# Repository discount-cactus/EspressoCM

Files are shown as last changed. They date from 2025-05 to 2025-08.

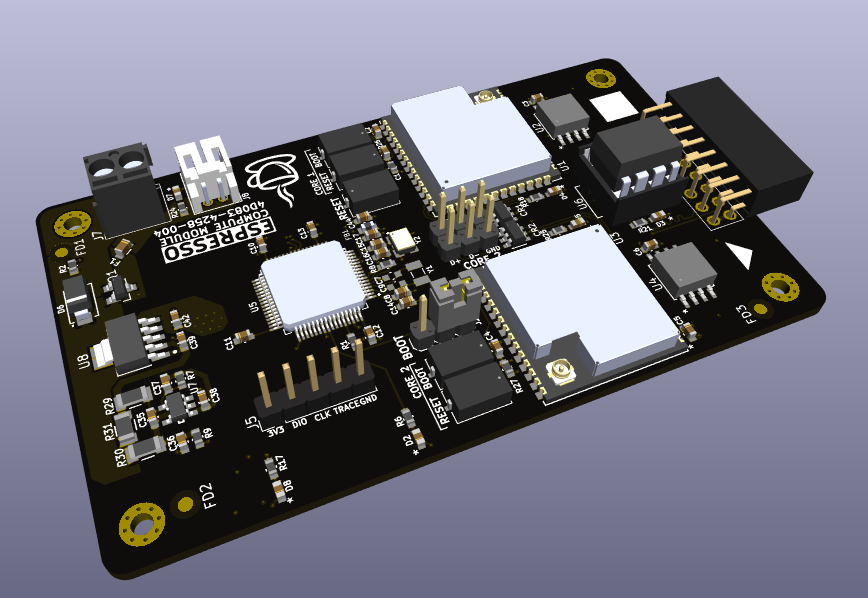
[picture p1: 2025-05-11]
cad_render.png

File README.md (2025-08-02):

# EspressoCM
Espresso Rev 4 CM, or just Espresso CM, is an STM32- and ESP32-based compute module for high performance networking and automation applications. The board was designed to provide a plethora of capabilities in a small, user-friendly and cheap package. An STM32 and two (not one but two!) ESP32's were chosen for their ease-of-use, clock speed and peripherals to acommodate these requirements. For the beginner or novel hobbyist, the ESP32's can be used - both come with their own dedicated flash memory chip as well as Wi-Fi and Bluetooth connectivity. For the more advanced and tech-savy, the STM32 can be programmed directly for higher-performance control.

Link to EspressoCM's complimentary library: https://github.com/discount-cactus/EspressoCMlib



## Board Statistics
- Dimensions: 84.9mm x 50.2mm
- Layers: 4
- Components: 83
- Mounting Hole Size: M2

## Features
- 1 x STM32F107 (@72MHz)
- 2 x ESP32-S3 (@240MHz)
- 1 x ATtiny85
- 1.5A linear regulator (VIN: 3-20V)
- Automatic power switchover from terminal block `J7` and JST battery connector `J8`
- JST LiPo Battery Connector
- 128Mbit Flash (one per ESP32)
- Dedicated E2B functionality
- On-board current sensing

## Applications
- Smart Homes
- Home networks
- IoT Connectivity
- Home automation
- Sensor monitoring

## Programming
### STM32
- The STM32 is programmed on-board via the pin connector `J5` with an ST-Link V2.
- Verify STM32CubeIDE is up-to-date
- Verify ST-Link V2 is up-to-date
1. Set BOOT0 to HIGH
2. Push reset button
3. Build code
4. Run code
5. Set BOOT0 to LOW
6. Push reset button

### ESP32
- The ESP32's are programmed on-board via the header pins `J3` (for Core 1) and `J4` (for Core 2). Pins are labeled on silkscreen.

### ATtiny85
- The ATtiny85 is programmed off-board.

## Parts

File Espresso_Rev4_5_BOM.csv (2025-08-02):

# | Reference | Qty | Value | Footprint | Manufacturer | Part Number | Alt Part Number | Rating | Color | DNP | Voltage Rating
1 | C14 | 1 | 4.7uF | Custom_Microcontroller:C_0603 | Samsung | CL10A475MA8NQNC |  | 25V
2 | C40 | 1 | 4.7nF | Custom_Microcontroller:C_1206 | KEMET | C1206C472KDRACAUTO |  | 1kV |  | DNP
3 | C1,C4 | 2 | 1uF | Custom_Microcontroller:C_0603 | Samsung | CL10A105KB8NNNC |  | 50V
4 | C15,C16 | 2 | 20pF | Custom_Microcontroller:C_0603 | Samsung | CL10C200JB8NNNC |  | 50V
5 | C2,C3,C5,C6,C8,C10,C11,C12,C13,C17,C38,C44 | 12 | 100nF | Custom_Microcontroller:C_0603 | Samsung | CL10B104KB8NNNC |  | 50V
6 | C35,C36,C37 | 3 | 220pF | Custom_Microcontroller:C_0603 | Samsung | CL10B221KB8NFNC | C0603C221J5HACAUTO | 50V
7 | C39,C42 | 2 | 10uF | Custom_Microcontroller:C_0603 | Samsung | CL10A106MA8NRNC |  | 25V
8 | C7,C9 | 2 | 8pF | Custom_Microcontroller:C_0603 | Samsung | CL10C080DB81PNC |  | 50V |  | DNP
9 | CR1,CR2 | 2 | USBLC6-2SC6 | Custom_Microcontroller:USBLC6-2SC6 | STMicroelectronics | USBLC6-2SC6
10 | D6 | 1 | ~ | Custom_Microcontroller:SK54AHE3-LTP | MCC | SK54AHE3-LTP
11 | D1,D4,D5 | 3 | ~ | Custom_Microcontroller:LED_0603 | Lite-On Inc. | LTST-C191KGKT |  |  | Green
12 | D2,D3,D7,D8 | 4 | ~ | Custom_Microcontroller:LED_0603 | Lite-On Inc. | LTST-C191KFKT |  |  | Orange
13 | F1 | 1 | 1A | Custom_Microcontroller:MF-FSMF050X-2 | Bourns | MF-FSMF050X-2
14 | FB1 | 1 | 120R | Custom_Microcontroller:FB_0603 | Murata | BLM18KG121TN1D
15 | J1 | 1 | ~ | Custom_Microcontroller:2X8 | Sullins | PPTC082LJBN-RC
16 | J5 | 1 | Conn_01x05 | Connector_PinHeader_2.54mm:PinHeader_1x05_P2.54mm_Vertical
17 | J6 | 1 | 20021321-00030T4LF | Custom_Microcontroller:20021321-00030T4LF | Amphenol | 20021321-00030T4LF
18 | J7 | 1 | OSTTE020104 | Custom_Microcontroller:OSTTE020104 | On Shore Technology | OSTTE020104 |  | 10A
19 | J8 | 1 | S2B-PH-K-S | Custom_Microcontroller:S2B-PH-K-S | JST | S2B-PH-K-S
20 | J2,J3,J4 | 3 | ~ | Custom_Microcontroller:1X3
21 | Q1 | 1 | ~ | Custom_Microcontroller:DMP3099L-7 | Diodes | DMP3099L-7
22 | R2 | 1 | 100K | Custom_Microcontroller:R_0603 | Stackpole | RMCF0603FT100K |  | 1/10W
23 | R3 | 1 | 1M00 | Custom_Microcontroller:R_1206 | Stackpole | RMCF1206FG1M00 |  | 1/4W |  | DNP
24 | R8 | 1 | 1M00 | Custom_Microcontroller:R_0603 | Stackpole | RMCF0603FT1M00 |  | 1/10W
25 | R31 | 1 | 3mOhm | Custom_Microcontroller:R_1206 | Rohm Semiconductor | PMR18EZPFV3L00 |  | 1W
26 | R1,R26,R27 | 3 | 10K | Custom_Microcontroller:R_0603 | Stackpole | RMCF0603FT10K0 |  | 1/10W
27 | R29,R30 | 2 | 97R6 | Custom_Microcontroller:R_1206 | KOA Speer | RK73H2BTTD97R6F |  | 1/4W
28 | R4,R22,R23,R28 | 4 | 4K7 | Custom_Microcontroller:R_1206 | Stackpole | RMCF1206FT4K70 |  | 1/4W
29 | R5,R6,R17,R18,R21,R24,R25 | 7 | 1K | Custom_Microcontroller:R_0603 | Stackpole | RMCF0603FT1K00 |  | 1/10W
30 | R7,R9 | 2 | 73K2 | Custom_Microcontroller:R_0603 | Stackpole | RMCF0603FT73K2 |  | 1/10W
31 | SW1,SW2,SW3,SW4,SW5 | 5 | ~ | Custom_Microcontroller:PTS636 SK25J SMTR LFS | C&K | PTS636SK25JSMTR LFS
32 | U5 | 1 | STM32F107RCT6TR | Custom_Microcontroller:STM32F107RCT6TR | STMicroelectronics | STM32F107RCT6TR
33 | U6 | 1 | ATTINY85-20PU | Custom_Microcontroller:ATTINY85-20PU | Microchip | ATTINY85-20PU
34 | U7 | 1 | INA180A2QDBVRQ1 | Custom_Microcontroller:INA180A2QDBVRQ1 | Texas Instruments | INA180A2QDBVRQ1
35 | U8 | 1 | TPS7A4533DCQR | Custom_Microcontroller:TPS7A4533DCQR | Texas Instruments | TPS7A4533DCQR
36 | U1,U3 | 2 | ESP32-S3-WROOM-1U-N8R2 | Custom_Microcontroller:ESP32-S3-WROOM-1U-N8R2 | Espressiff | ESP32-S3-WROOM-1U-N8R2
37 | U2,U4 | 2 | ~ | Custom_Microcontroller:W25Q128JVSIQ | Winbond | W25Q128JVSIQ
38 | Y1 | 1 | 32.768 kHz | Custom_Microcontroller:ECS-.327-9-34B-TR | ECS | ECS-.327-9-34B-TR |  |  |  | DNP
39 | Y2 | 1 | 25MHz | Custom_Microcontroller:ECS-2333-250-BN-TR | ECS | ECS-250-20-33-CKM-TR3

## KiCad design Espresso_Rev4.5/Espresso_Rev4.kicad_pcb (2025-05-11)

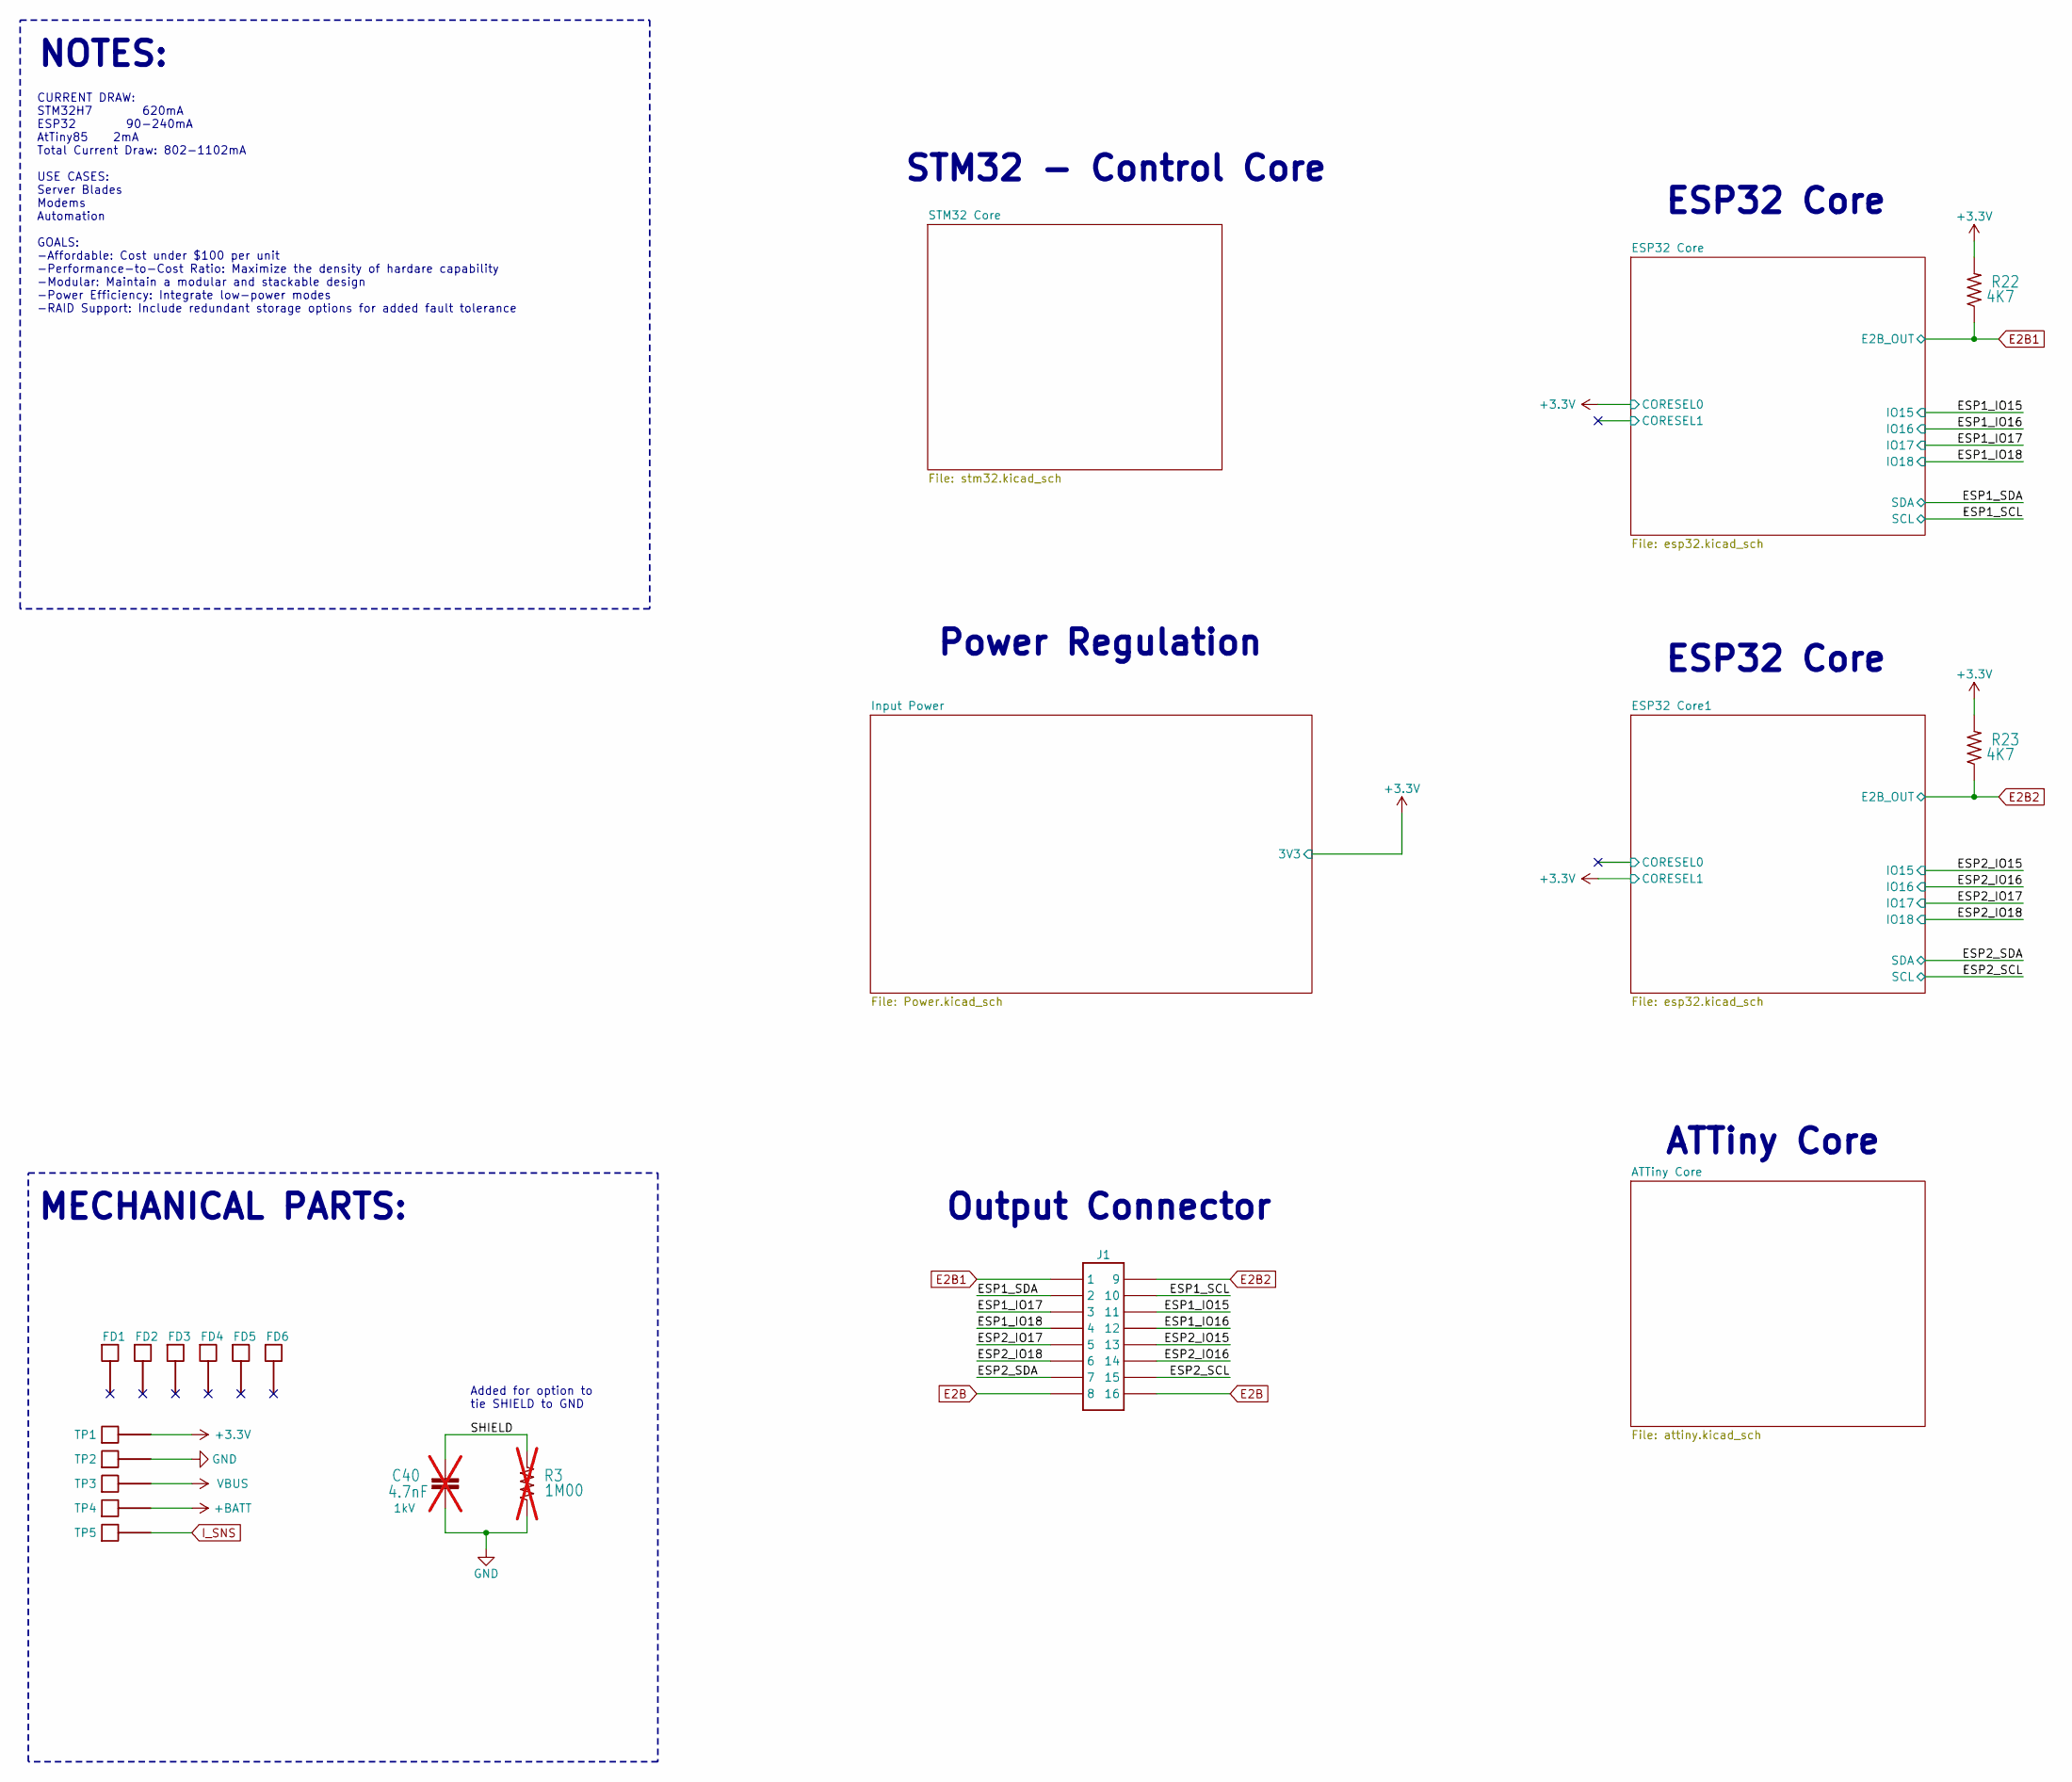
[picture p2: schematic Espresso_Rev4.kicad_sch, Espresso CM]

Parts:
C40: 4.7nF; C_1206; Rating 1kV; Part Number C1206C472KDRACAUTO; not fitted
FD1, FD2, FD3, FD4, FD5, FD6: Fiducial_1.5mm_Mask3mm
J1: 2X8; Part Number PPTC082LJBN-RC
R3: 1M00; R_1206; Rating 1/4W; Part Number RMCF1206FG1M00; not fitted
R22, R23: 4K7; R_1206; Rating 1/4W; Part Number RMCF1206FT4K70
TP1, TP2, TP3, TP4, TP5: TESTPOINT

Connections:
+3.3V: R22.2, R23.2, TP1.1; also elsewhere on the board
+BATT: TP4.1; also elsewhere on the board
/ESP1_IO15: J1.11; also elsewhere on the board
/ESP1_IO16: J1.12; also elsewhere on the board
/ESP1_IO17: J1.3; also elsewhere on the board
/ESP1_IO18: J1.4; also elsewhere on the board
/ESP1_SCL: J1.10; also elsewhere on the board
/ESP1_SDA: J1.2; also elsewhere on the board
/ESP2_IO15: J1.13; also elsewhere on the board
/ESP2_IO16: J1.14; also elsewhere on the board
/ESP2_IO17: J1.5; also elsewhere on the board
/ESP2_IO18: J1.6; also elsewhere on the board
/ESP2_SCL: J1.15; also elsewhere on the board
/ESP2_SDA: J1.7; also elsewhere on the board
/SHIELD: C40.1, R3.2; also elsewhere on the board
E2B: J1.8, J1.16; also elsewhere on the board
E2B1: J1.1, R22.1; also elsewhere on the board
E2B2: J1.9, R23.1; also elsewhere on the board
GND: C40.2, R3.1, TP2.1; also elsewhere on the board
I_SNS: TP5.1; also elsewhere on the board
VBUS: TP3.1; also elsewhere on the board

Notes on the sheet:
MECHANICAL PARTS:
Power Regulation
Added for option to tie SHIELD to GND
Output Connector
ESP32 Core
NOTES:
CURRENT DRAW: STM32H7 620mA ESP32 90-240mA AtTiny85 2mA Total Current Draw: 802-1102mA USE CASES: Server Blades Modems Automation GOALS: -Affordable: Cost under $100 per unit -Performance-to-Cost Ratio: Maximize the density of hardare capability -Modular: Maintain a modular and stackable design -Po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
ATTiny Core
STM32 - Control Core

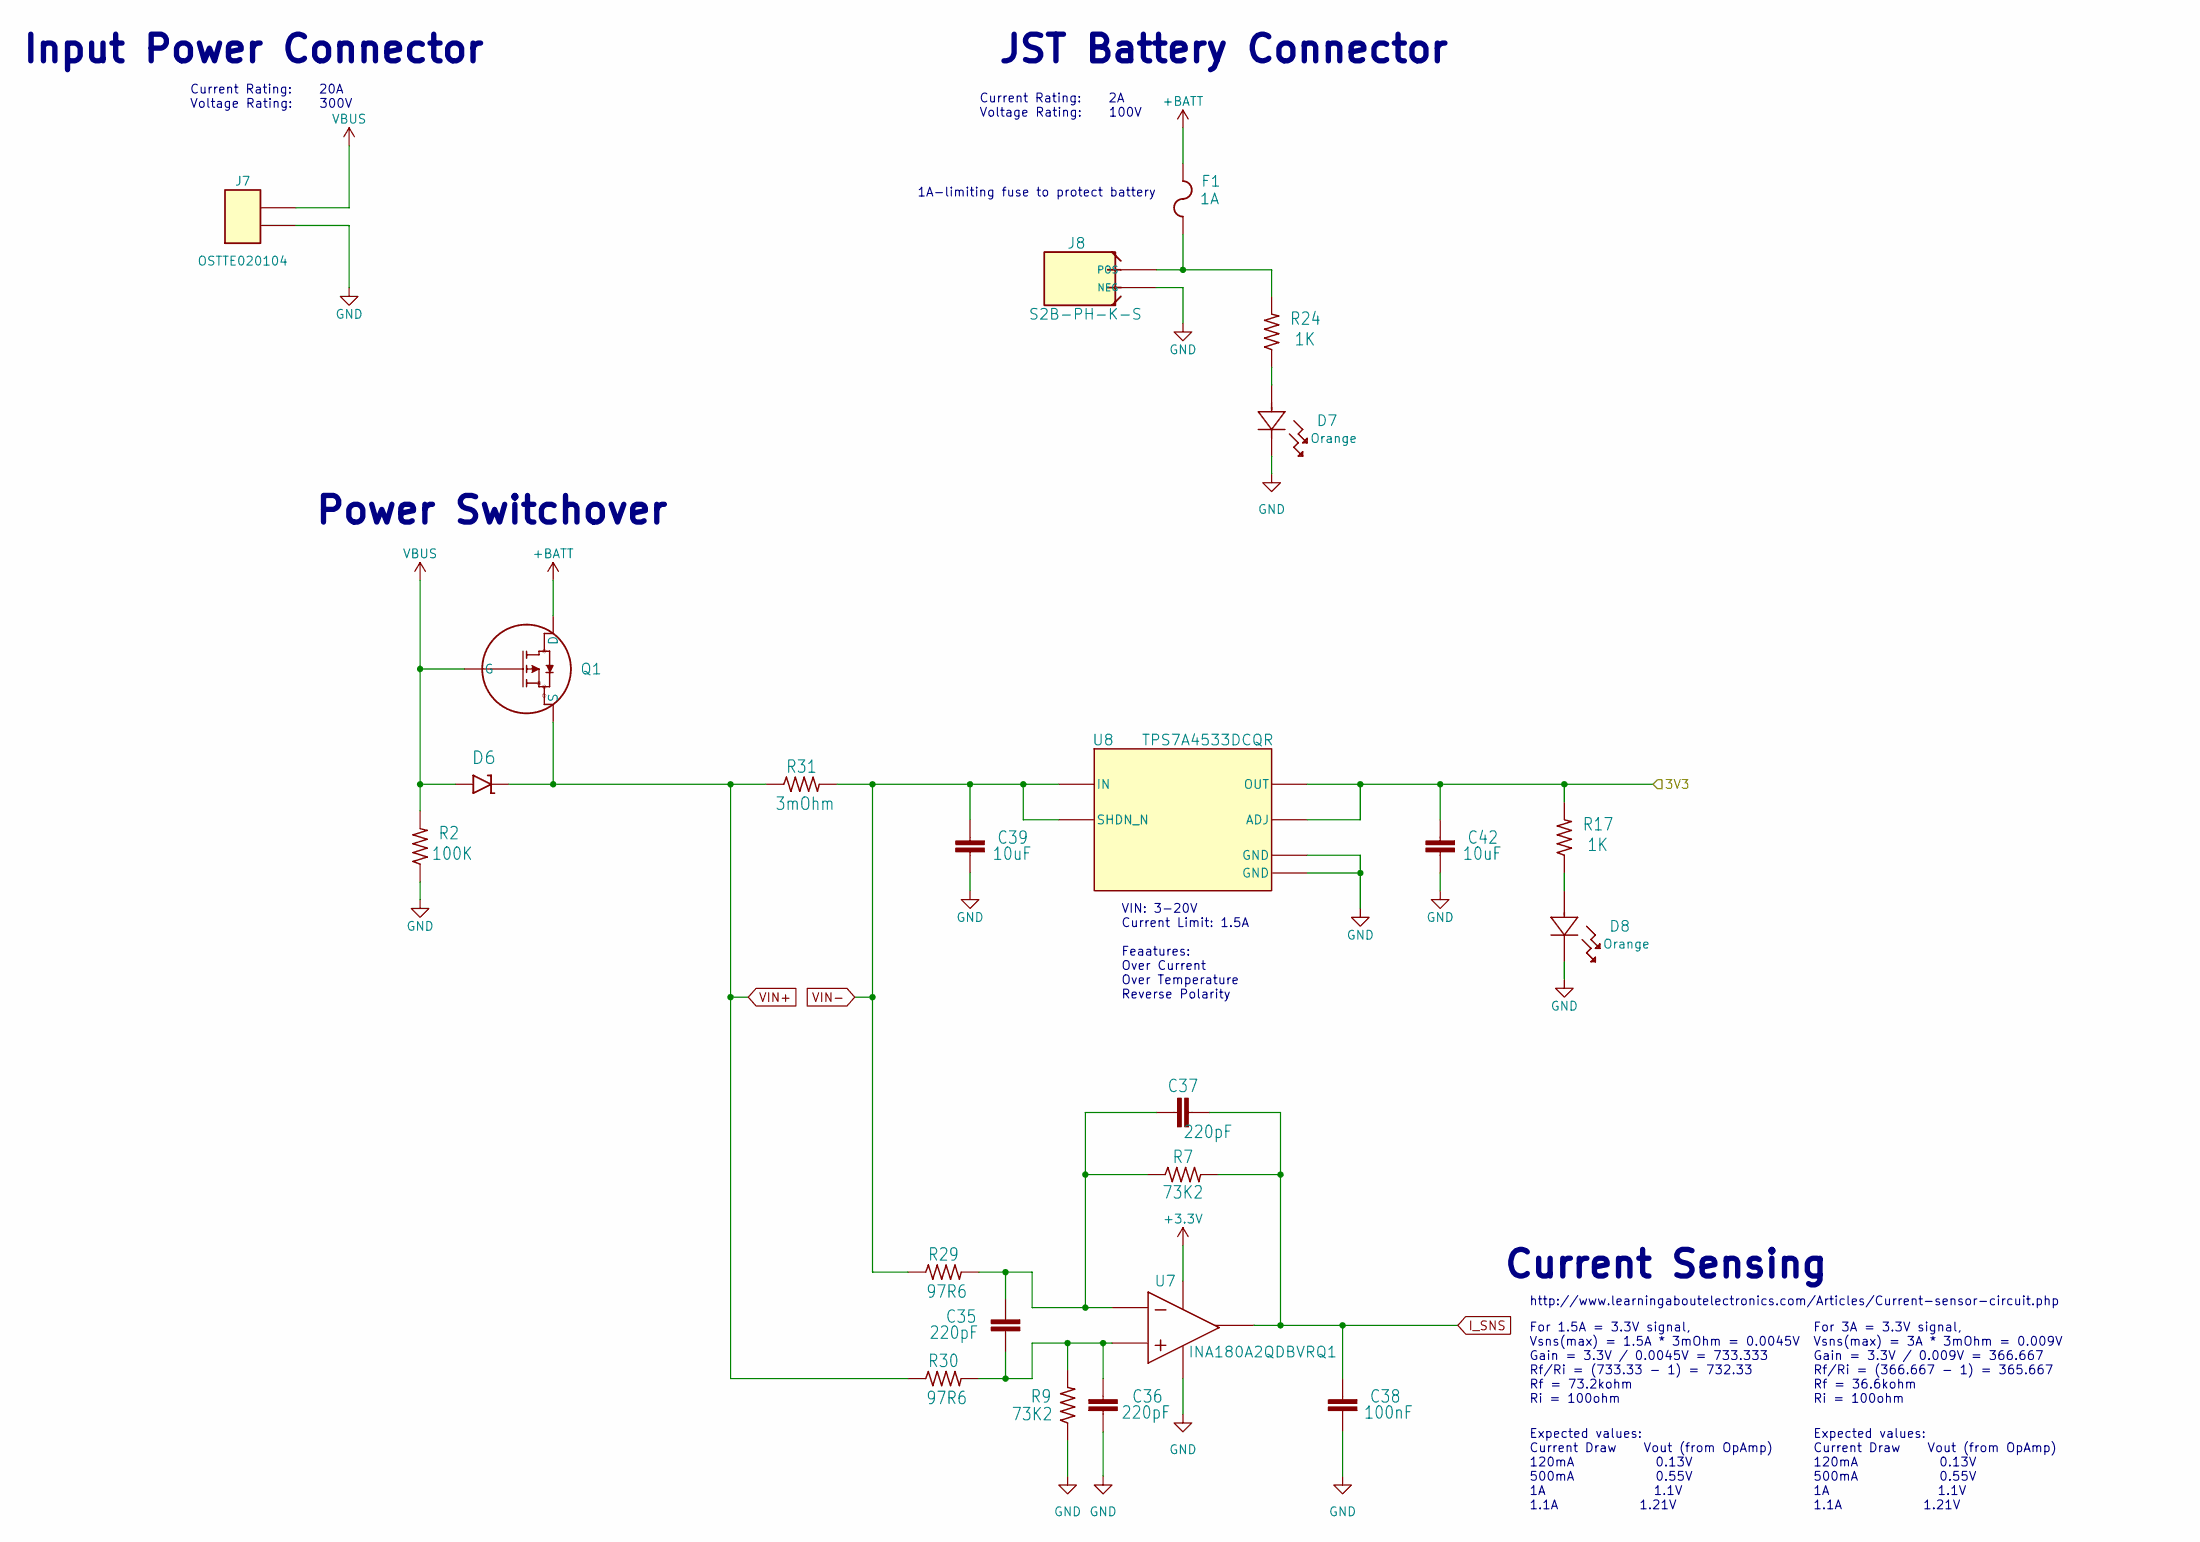
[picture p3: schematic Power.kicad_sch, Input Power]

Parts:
C35, C36, C37: 220pF; C_0603; Rating 50V; Part Number CL10B221KB8NFNC
C38: 100nF; C_0603; Rating 50V; Part Number CL10B104KB8NNNC
C39, C42: 10uF; C_0603; Rating 25V; Part Number CL10A106MA8NRNC
D6: SK54AHE3-LTP; Part Number SK54AHE3-LTP
D7, D8: LED_0603; Part Number LTST-C191KFKT
F1: 1A; MF-FSMF050X-2; Part Number MF-FSMF050X-2
J7: OSTTE020104; Rating 10A; Part Number OSTTE020104
J8: S2B-PH-K-S; Part Number S2B-PH-K-S
Q1: DMP3099L-7; Part Number DMP3099L-7
R2: 100K; R_0603; Rating 1/10W; Part Number RMCF0603FT100K
R7, R9: 73K2; R_0603; Rating 1/10W; Part Number RMCF0603FT73K2
R17, R24: 1K; R_0603; Rating 1/10W; Part Number RMCF0603FT1K00
R29, R30: 97R6; R_1206; Rating 1/4W; Part Number RK73H2BTTD97R6F
R31: 3mOhm; R_1206; Rating 1W; Part Number PMR18EZPFV3L00
U7: INA180A2QDBVRQ1; Part Number INA180A2QDBVRQ1
U8: TPS7A4533DCQR; Part Number TPS7A4533DCQR

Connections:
+3.3V: C42.2, R17.2, U7.5 (V+), U8.4 (OUT), U8.5 (ADJ); also elsewhere on the board
+BATT: F1.2, Q1.3 (D); also elsewhere on the board
GND: C36.1, C38.1, C39.1, C42.1, D7.1, D8.1, J7.1, J8.2 (NEG), R2.1, R9.1, U7.2 (V-), U8.3 (GND), U8.6 (GND); also elsewhere on the board
I_SNS: C37.2, C38.2, R7.2, U7.1 (OUT); also elsewhere on the board
unnamed: D7.2, R24.1
unnamed: D8.2, R17.1
unnamed: F1.1, J8.1 (POS), R24.2
unnamed: C35.1, C36.2, R9.2, R30.2, U7.3 (IN+)
unnamed: C35.2, C37.1, R7.1, R29.2, U7.4 (IN-)
VBUS: D6.2, J7.2, Q1.1 (G), R2.2; also elsewhere on the board
VIN+: D6.1, Q1.2 (S), R30.1, R31.1
VIN-: C39.2, R29.1, R31.2, U8.1 (SHDN_N), U8.2 (IN)

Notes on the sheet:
http://www.learningaboutelectronics.com/Articles/Current-sensor-circuit.php
VIN: 3-20V Current Limit: 1.5A Feaatures: Over Current Over Temperature Reverse Polarity
1A-limiting fuse to protect battery
Expected values: Current Draw Vout (from OpAmp) 120mA 0.13V 500mA 0.55V 1A 1.1V 1.1A 1.21V
For 1.5A = 3.3V signal, Vsns(max) = 1.5A * 3mOhm = 0.0045V Gain = 3.3V / 0.0045V = 733.333 Rf/Ri = (733.33 - 1) = 732.33 Rf = 73.2kohm Ri = 100ohm
Power Switchover
For 3A = 3.3V signal, Vsns(max) = 3A * 3mOhm = 0.009V Gain = 3.3V / 0.009V = 366.667 Rf/Ri = (366.667 - 1) = 365.667 Rf = 36.6kohm Ri = 100ohm
Current Rating: 2A Voltage Rating: 100V
Current Rating: 20A Voltage Rating: 300V
JST Battery Connector
Current Sensing
Input Power Connector

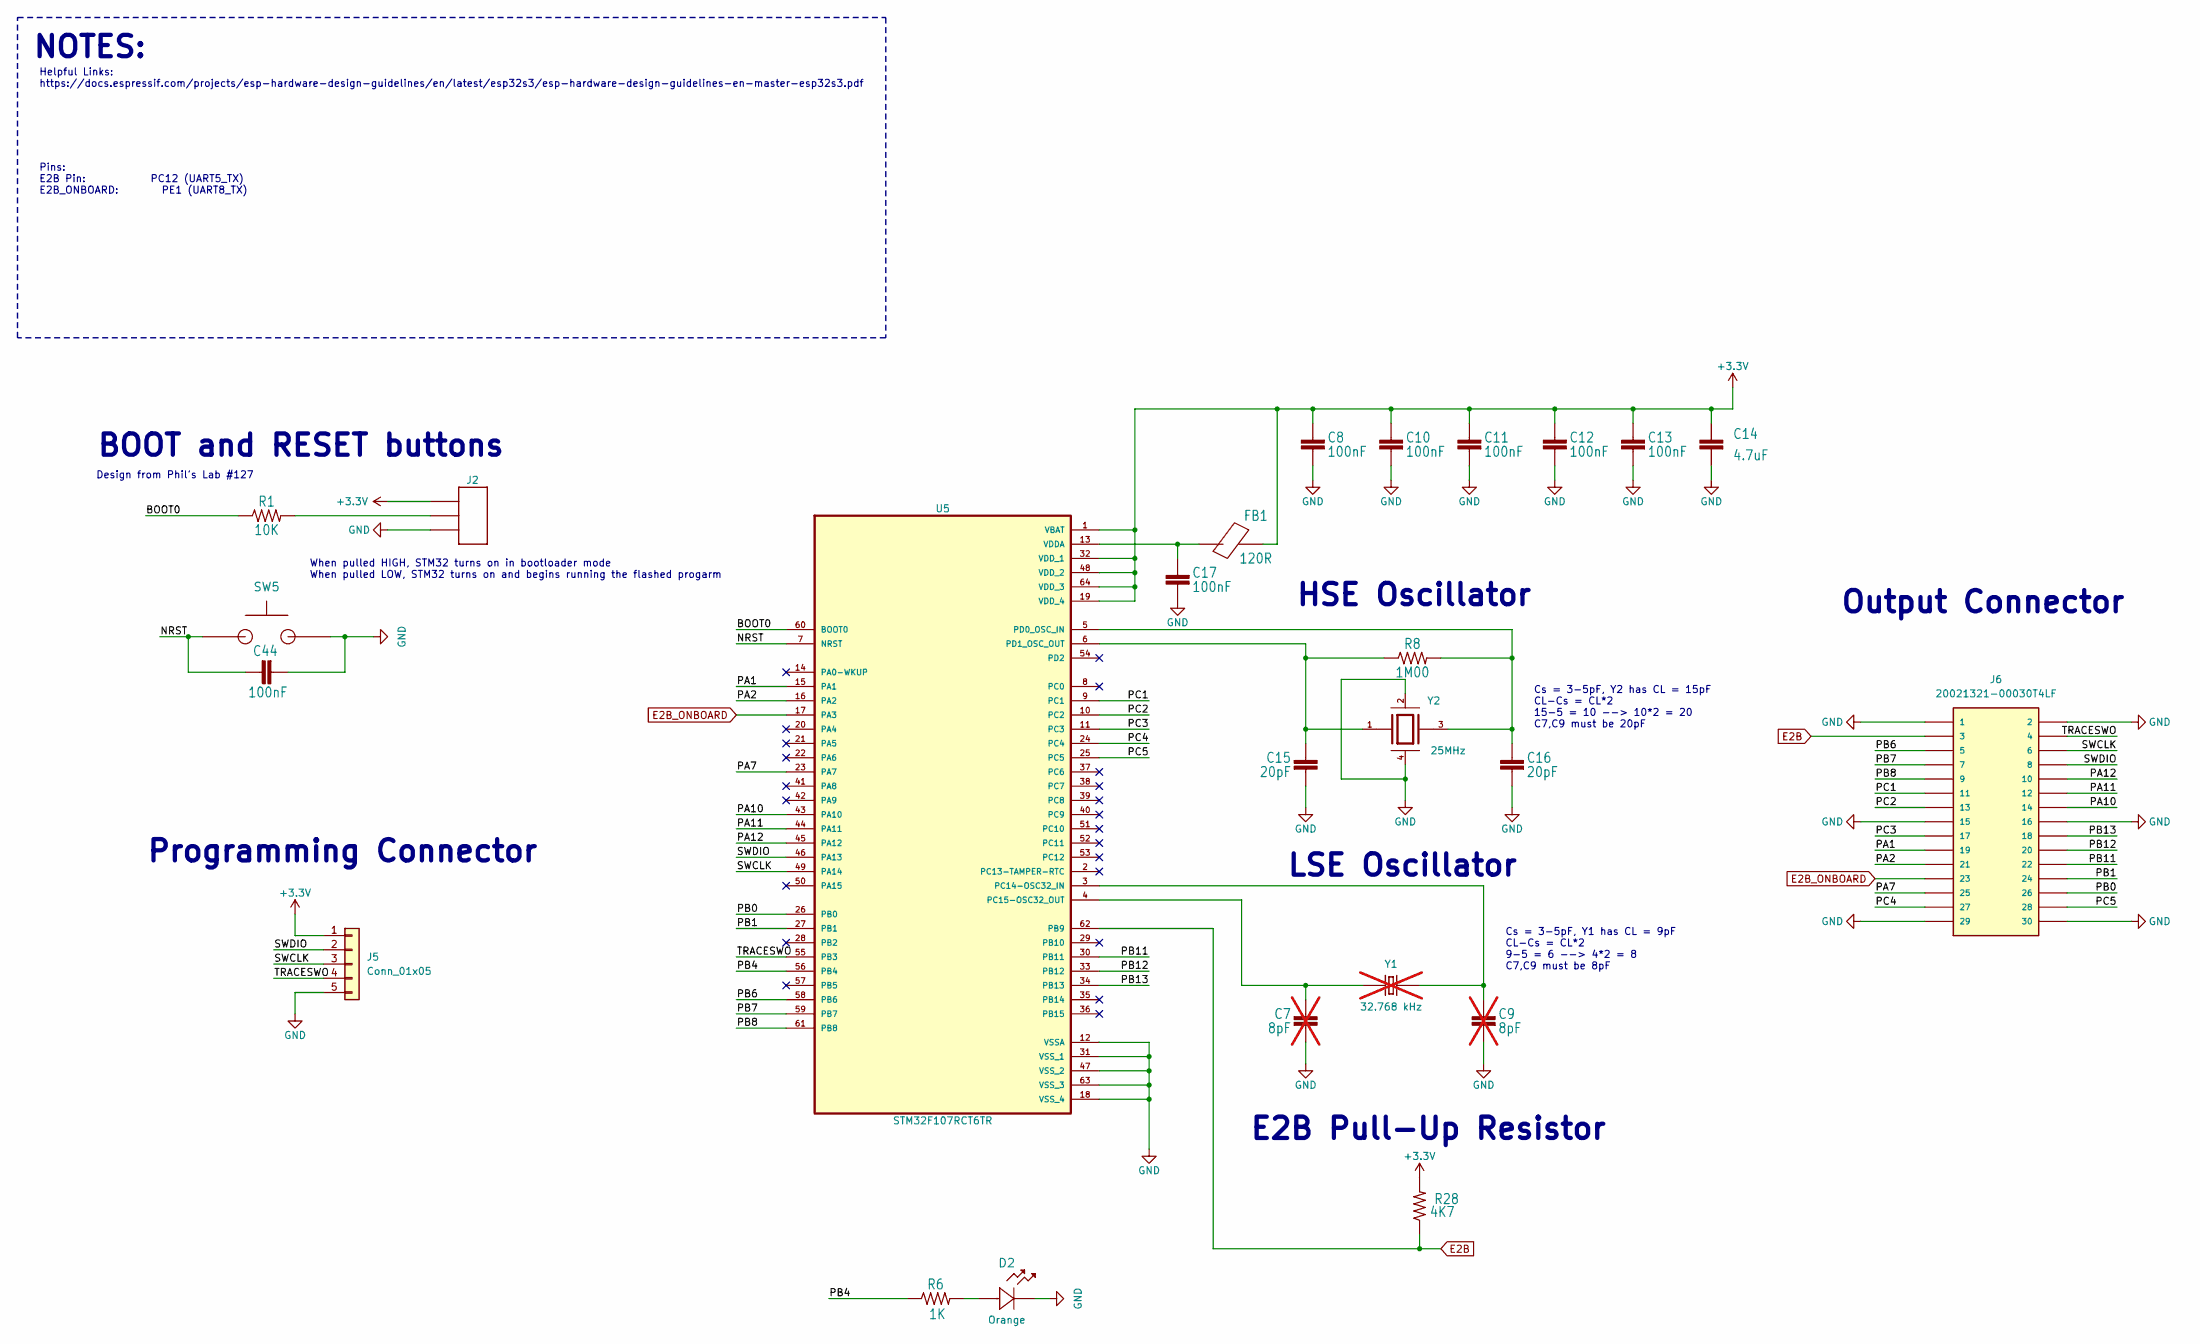
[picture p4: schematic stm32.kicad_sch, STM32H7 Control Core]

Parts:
C7, C9: 8pF; C_0603; Rating 50V; Part Number CL10C080DB81PNC; not fitted
C8, C10, C11, C12, C13, C17, C44: 100nF; C_0603; Rating 50V; Part Number CL10B104KB8NNNC
C14: 4.7uF; C_0603; Rating 25V; Part Number CL10A475MA8NQNC
C15, C16: 20pF; C_0603; Rating 50V; Part Number CL10C200JB8NNNC
D2: LED_0603; Part Number LTST-C191KFKT
FB1: 120R; FB_0603; Part Number BLM18KG121TN1D
J2: 1X3
J5: Conn_01x05; PinHeader_1x05_P2.54mm_Vertical
J6: 20021321-00030T4LF; Part Number 20021321-00030T4LF
R1: 10K; R_0603; Rating 1/10W; Part Number RMCF0603FT10K0
R6: 1K; R_0603; Rating 1/10W; Part Number RMCF0603FT1K00
R8: 1M00; R_0603; Rating 1/10W; Part Number RMCF0603FT1M00
R28: 4K7; R_1206; Rating 1/4W; Part Number RMCF1206FT4K70
SW5: PTS636 SK25J SMTR LFS; Part Number PTS636SK25JSMTR LFS
U5: STM32F107RCT6TR; Part Number STM32F107RCT6TR
Y1: 32.768 kHz; ECS-.327-9-34B-TR; Part Number ECS-.327-9-34B-TR; not fitted
Y2: 25MHz; ECS-2333-250-BN-TR; Part Number ECS-2333-250-BN-TR

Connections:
+3.3V: C8.2, C10.2, C11.2, C12.2, C13.2, C14.2, FB1.2, J2.1, J5.1, R28.2, U5.1 (VBAT), U5.19 (VDD_4), U5.32 (VDD_1), U5.48 (VDD_2), U5.64 (VDD_3); also elsewhere on the board
/STM32 Core/BOOT0: R1.1, U5.60 (BOOT0)
/STM32 Core/NRST: C44.2, SW5.1, U5.7 (NRST)
/STM32 Core/PA1: J6.19, U5.15 (PA1)
/STM32 Core/PA2: J6.21, U5.16 (PA2)
/STM32 Core/PA7: J6.25, U5.23 (PA7)
/STM32 Core/PA10: J6.14, U5.43 (PA10)
/STM32 Core/PA11: J6.12, U5.44 (PA11)
/STM32 Core/PA12: J6.10, U5.45 (PA12)
/STM32 Core/PB0: J6.26, U5.26 (PB0)
/STM32 Core/PB1: J6.24, U5.27 (PB1)
/STM32 Core/PB4: R6.1, U5.56 (PB4)
/STM32 Core/PB6: J6.5, U5.58 (PB6)
/STM32 Core/PB7: J6.7, U5.59 (PB7)
/STM32 Core/PB8: J6.9, U5.61 (PB8)
/STM32 Core/PB11: J6.22, U5.30 (PB11)
/STM32 Core/PB12: J6.20, U5.33 (PB12)
/STM32 Core/PB13: J6.18, U5.34 (PB13)
/STM32 Core/PC1: J6.11, U5.9 (PC1)
/STM32 Core/PC2: J6.13, U5.10 (PC2)
/STM32 Core/PC3: J6.17, U5.11 (PC3)
/STM32 Core/PC4: J6.27, U5.24 (PC4)
/STM32 Core/PC5: J6.28, U5.25 (PC5)
/STM32 Core/SWCLK: J5.3, J6.6, U5.49 (PA14)
/STM32 Core/SWDIO: J5.2, J6.8, U5.46 (PA13)
/STM32 Core/TRACESWO: J5.4, J6.4, U5.55 (PB3)
E2B: J6.3, R28.1, U5.62 (PB9); also elsewhere on the board
E2B_ONBOARD: J6.23, U5.17 (PA3); also elsewhere on the board
GND: C7.1, C8.1, C9.1, C10.1, C11.1, C12.1, C13.1, C14.1, C15.1, C16.1, C17.1, C44.1, D2.1, J2.3, J5.5, J6.1, J6.2, J6.15, J6.16, J6.29, J6.30, SW5.2, U5.12 (VSSA), U5.18 (VSS_4), U5.31 (VSS_1), U5.47 (VSS_2), U5.63 (VSS_3), Y2.2 (GND), Y2.4 (GND); also elsewhere on the board
unnamed: D2.2, R6.2
unnamed: J2.2, R1.2
unnamed: C9.2, U5.3 (PC14-OSC32_IN), Y1.2
unnamed: C7.2, U5.4 (PC15-OSC32_OUT), Y1.1
unnamed: C16.2, R8.2, U5.5 (PD0_OSC_IN), Y2.3 (OUT)
unnamed: C15.2, R8.1, U5.6 (PD1_OSC_OUT), Y2.1 (IN)
unnamed: C17.2, FB1.1, U5.13 (VDDA)

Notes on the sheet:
HSE Oscillator
E2B Pull-Up Resistor
Pins: E2B Pin: PC12 (UART5_TX) E2B_ONBOARD: PE1 (UART8_TX)
Design from Phil's Lab #127
Output Connector
NOTES:
When pulled HIGH, STM32 turns on in bootloader mode When pulled LOW, STM32 turns on and begins running the flashed progarm
LSE Oscillator
Cs = 3-5pF, Y2 has CL = 15pF CL-Cs = CL*2 15-5 = 10 --> 10*2 = 20 C7,C9 must be 20pF
Cs = 3-5pF, Y1 has CL = 9pF CL-Cs = CL*2 9-5 = 6 --> 4*2 = 8 C7,C9 must be 8pF
Programming Connector
BOOT and RESET buttons
Helpful Links: https://docs.espressif.com/projects/esp-hardware-design-guidelines/en/latest/esp32s3/esp-hardware-design-guidelines-en-master-esp32s3.pdf

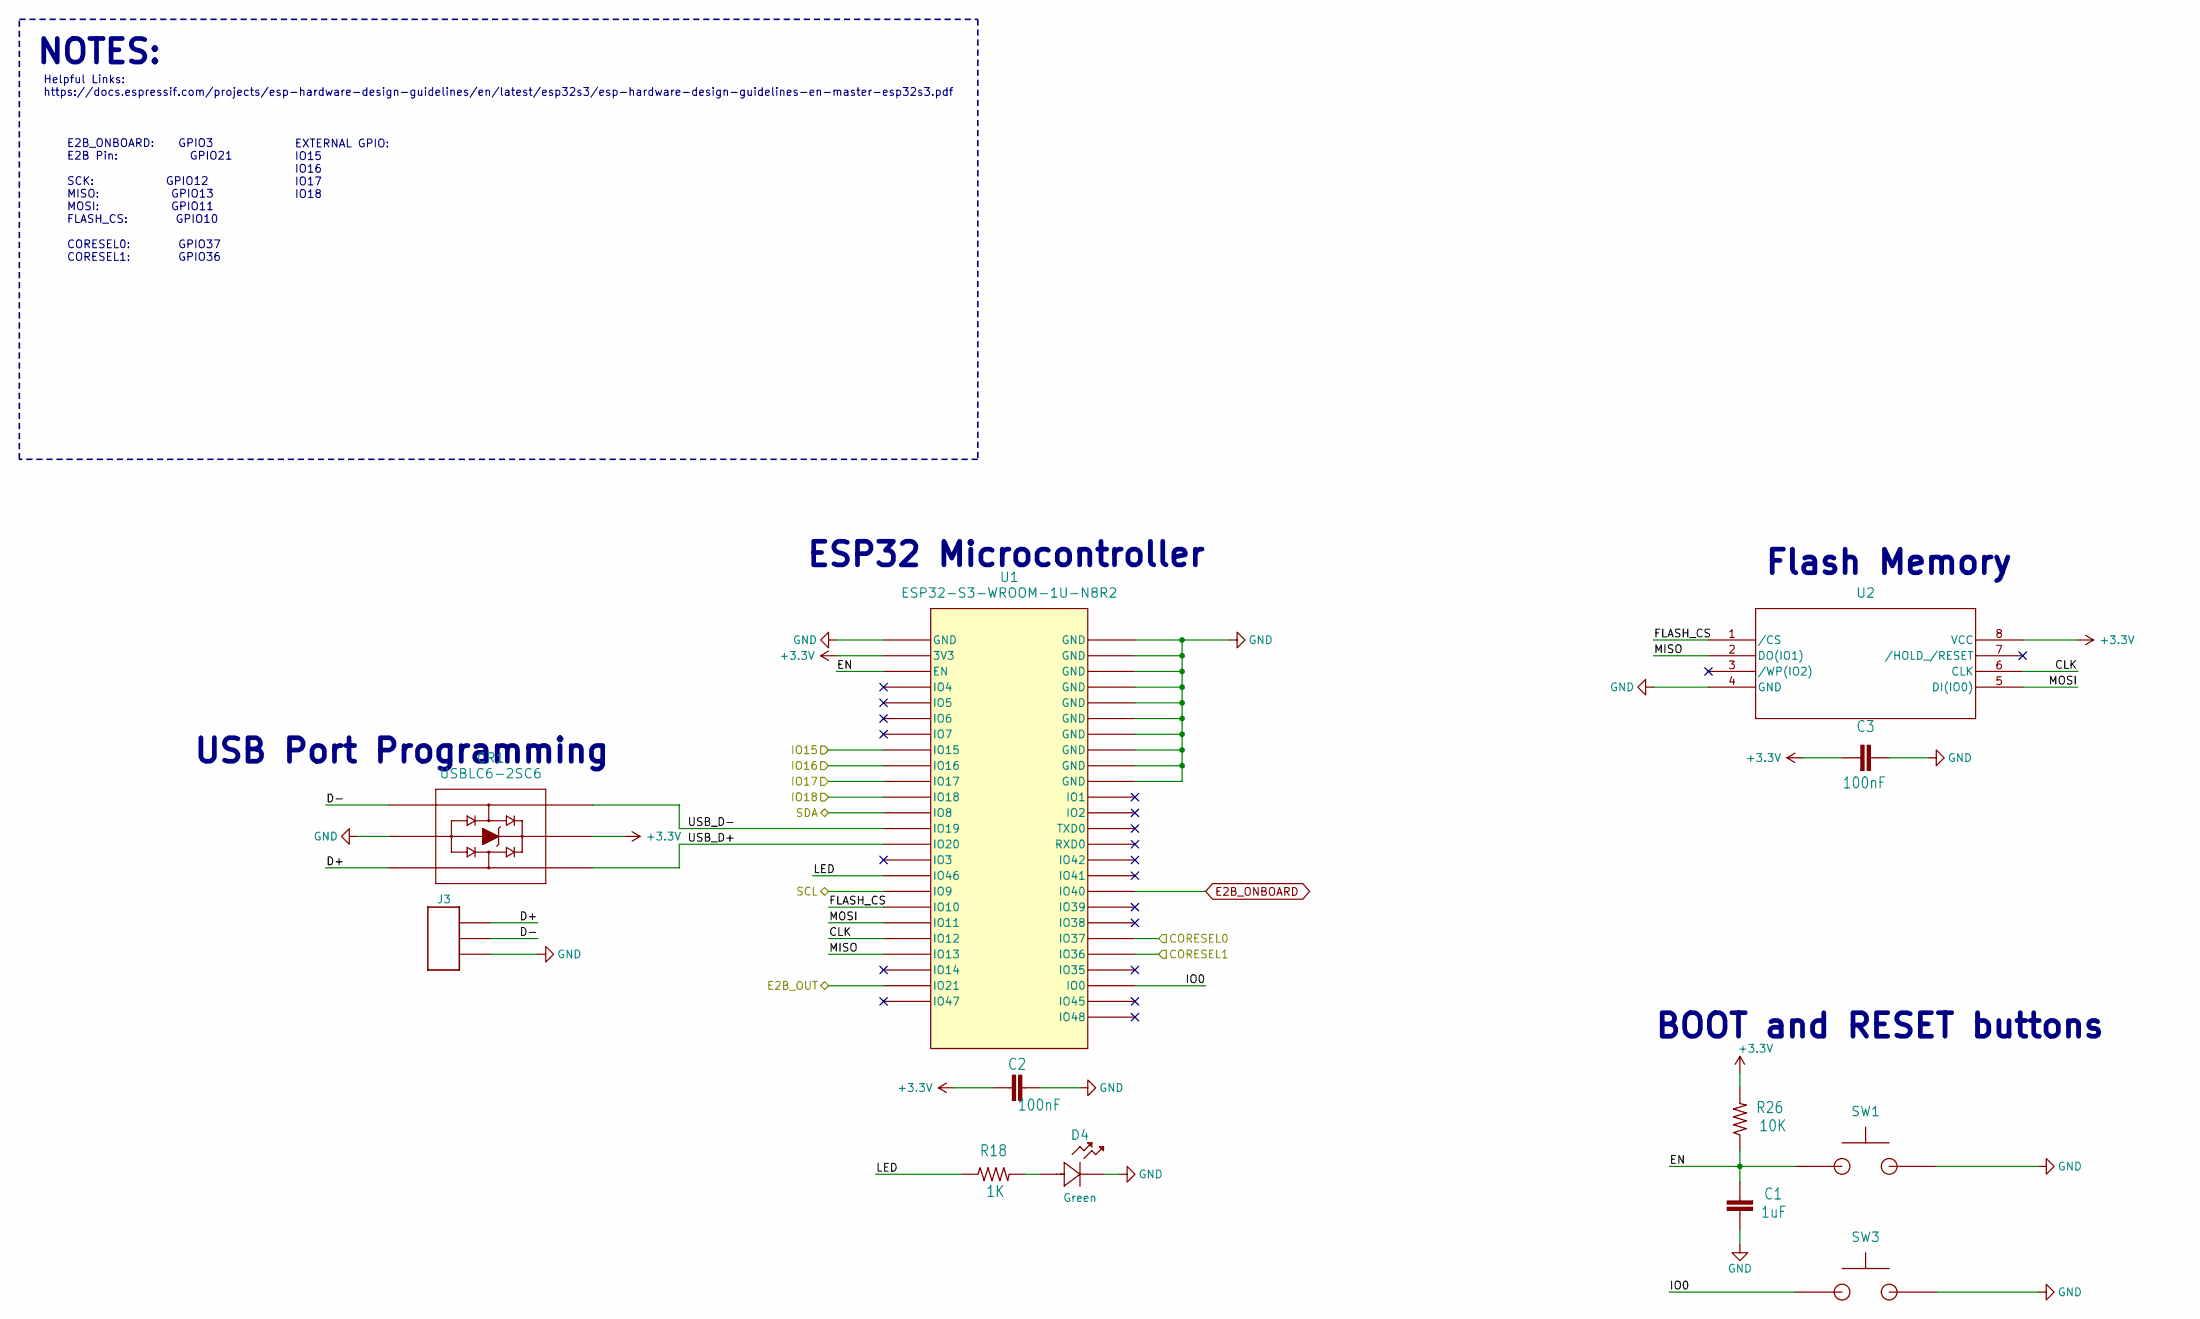
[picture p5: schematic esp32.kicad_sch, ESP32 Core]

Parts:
C1: 1uF; C_0603; Rating 50V; Part Number CL10A105KB8NNNC
C2, C3: 100nF; C_0603; Rating 50V; Part Number CL10B104KB8NNNC
CR1: USBLC6-2SC6; Part Number USBLC6-2SC6
D4: LED_0603; Part Number LTST-C191KGKT
J3: 1X3
R18: 1K; R_0603; Rating 1/10W; Part Number RMCF0603FT1K00
R26: 10K; R_0603; Rating 1/10W; Part Number RMCF0603FT10K0
SW1, SW3: PTS636 SK25J SMTR LFS; Part Number PTS636SK25JSMTR LFS
U1: ESP32-S3-WROOM-1U-N8R2; Part Number ESP32-S3-WROOM-1U-N8R2
U2: W25Q128JVSIQ; Part Number W25Q128JVSIQ

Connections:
+3.3V: C2.1, C3.1, CR1.5, R26.2, U1.2 (3V3), U1.30 (IO37), U2.8 (VCC); also elsewhere on the board
/ESP1_IO15: U1.8 (IO15); also elsewhere on the board
/ESP1_IO16: U1.9 (IO16); also elsewhere on the board
/ESP1_IO17: U1.10 (IO17); also elsewhere on the board
/ESP1_IO18: U1.11 (IO18); also elsewhere on the board
/ESP1_SCL: U1.17 (IO9); also elsewhere on the board
/ESP1_SDA: U1.12 (IO8); also elsewhere on the board
/ESP32 Core/CLK: U1.20 (IO12), U2.6 (CLK)
/ESP32 Core/CORESEL1: U1.29 (IO36)
/ESP32 Core/D+: CR1.3, J3.1
/ESP32 Core/D-: CR1.1, J3.2
/ESP32 Core/EN: C1.2, R26.1, SW1.1, U1.3 (EN)
/ESP32 Core/FLASH_CS: U1.18 (IO10), U2.1 (/CS)
/ESP32 Core/IO0: SW3.1, U1.27 (IO0)
/ESP32 Core/LED: R18.1, U1.16 (IO46)
/ESP32 Core/MISO: U1.21 (IO13), U2.2 (DO(IO1))
/ESP32 Core/MOSI: U1.19 (IO11), U2.5 (DI(IO0))
/ESP32 Core/USB_D+: CR1.4, U1.14 (IO20)
/ESP32 Core/USB_D-: CR1.6, U1.13 (IO19)
E2B1: U1.23 (IO21); also elsewhere on the board
E2B_ONBOARD: U1.33 (IO40); also elsewhere on the board
GND: C1.1, C2.2, C3.2, CR1.2, D4.1, J3.3, SW1.2, SW3.2, U1.1 (GND), U1.40 (GND), U1.41 (GND), U1.42 (GND), U1.43 (GND), U1.44 (GND), U1.45 (GND), U1.46 (GND), U1.47 (GND), U1.48 (GND), U1.49 (GND), U2.4 (GND); also elsewhere on the board
unnamed: D4.2, R18.2

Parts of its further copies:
C4: 1uF; C_0603; Rating 50V; Part Number CL10A105KB8NNNC
C5, C6: 100nF; C_0603; Rating 50V; Part Number CL10B104KB8NNNC
CR2: USBLC6-2SC6; Part Number USBLC6-2SC6
D5: LED_0603; Part Number LTST-C191KGKT
J4: 1X3
R25: 1K; R_0603; Rating 1/10W; Part Number RMCF0603FT1K00
R27: 10K; R_0603; Rating 1/10W; Part Number RMCF0603FT10K0
SW2, SW4: PTS636 SK25J SMTR LFS; Part Number PTS636SK25JSMTR LFS
U3: ESP32-S3-WROOM-1U-N8R2; Part Number ESP32-S3-WROOM-1U-N8R2
U4: W25Q128JVSIQ; Part Number W25Q128JVSIQ

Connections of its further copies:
+3.3V: C5.1, C6.1, CR2.5, R27.2, U3.2 (3V3), U3.29 (IO36), U4.8 (VCC); also elsewhere on the board
/ESP2_IO15: U3.8 (IO15); also elsewhere on the board
/ESP2_IO16: U3.9 (IO16); also elsewhere on the board
/ESP2_IO17: U3.10 (IO17); also elsewhere on the board
/ESP2_IO18: U3.11 (IO18); also elsewhere on the board
/ESP2_SCL: U3.17 (IO9); also elsewhere on the board
/ESP2_SDA: U3.12 (IO8); also elsewhere on the board
/ESP32 Core1/CLK: U3.20 (IO12), U4.6 (CLK)
/ESP32 Core1/CORESEL0: U3.30 (IO37)
/ESP32 Core1/D+: CR2.3, J4.1
/ESP32 Core1/D-: CR2.1, J4.2
/ESP32 Core1/EN: C4.2, R27.1, SW2.1, U3.3 (EN)
/ESP32 Core1/FLASH_CS: U3.18 (IO10), U4.1 (/CS)
/ESP32 Core1/IO0: SW4.1, U3.27 (IO0)
/ESP32 Core1/LED: R25.1, U3.16 (IO46)
/ESP32 Core1/MISO: U3.21 (IO13), U4.2 (DO(IO1))
/ESP32 Core1/MOSI: U3.19 (IO11), U4.5 (DI(IO0))
/ESP32 Core1/USB_D+: CR2.4, U3.14 (IO20)
/ESP32 Core1/USB_D-: CR2.6, U3.13 (IO19)
E2B2: U3.23 (IO21); also elsewhere on the board
E2B_ONBOARD: U3.33 (IO40); also elsewhere on the board
GND: C4.1, C5.2, C6.2, CR2.2, D5.1, J4.3, SW2.2, SW4.2, U3.1 (GND), U3.40 (GND), U3.41 (GND), U3.42 (GND), U3.43 (GND), U3.44 (GND), U3.45 (GND), U3.46 (GND), U3.47 (GND), U3.48 (GND), U3.49 (GND), U4.4 (GND); also elsewhere on the board
unnamed: D5.2, R25.2

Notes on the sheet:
E2B_ONBOARD: GPIO3 E2B Pin: GPIO21 SCK: GPIO12 MISO: GPIO13 MOSI: GPIO11 FLASH_CS: GPIO10 CORESEL0: GPIO37 CORESEL1: GPIO36
EXTERNAL GPIO: IO15 IO16 IO17 IO18
BOOT and RESET buttons
NOTES:
Helpful Links: https://docs.espressif.com/projects/esp-hardware-design-guidelines/en/latest/esp32s3/esp-hardware-design-guidelines-en-master-esp32s3.pdf
Flash Memory
ESP32 Microcontroller
USB Port Programming

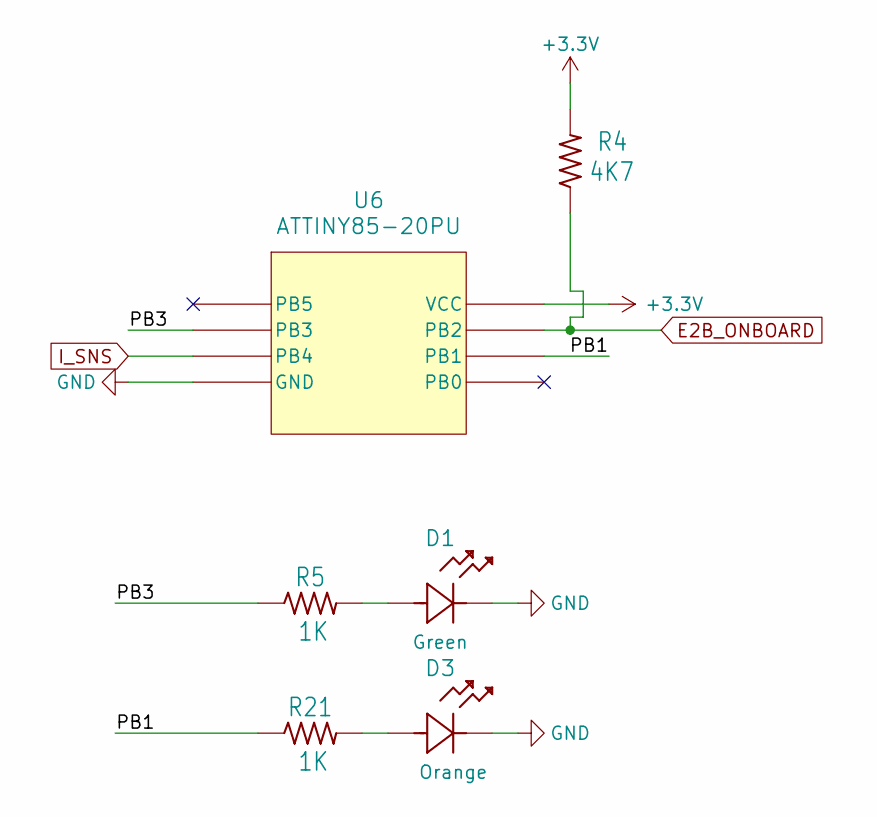
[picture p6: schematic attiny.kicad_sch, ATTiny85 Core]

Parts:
D1: LED_0603; Part Number LTST-C191KGKT
D3: LED_0603; Part Number LTST-C191KFKT
R4: 4K7; R_1206; Rating 1/4W; Part Number RMCF1206FT4K70
R5, R21: 1K; R_0603; Rating 1/10W; Part Number RMCF0603FT1K00
U6: ATTINY85-20PU; Part Number ATTINY85-20PU

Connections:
+3.3V: R4.2, U6.8 (VCC); also elsewhere on the board
/ATTiny Core/PB1: R21.1, U6.6 (PB1)
/ATTiny Core/PB3: R5.1, U6.2 (PB3)
E2B_ONBOARD: R4.1, U6.7 (PB2); also elsewhere on the board
GND: D1.1, D3.1, U6.4 (GND); also elsewhere on the board
I_SNS: U6.3 (PB4); also elsewhere on the board
unnamed: D1.2, R5.2
unnamed: D3.2, R21.2

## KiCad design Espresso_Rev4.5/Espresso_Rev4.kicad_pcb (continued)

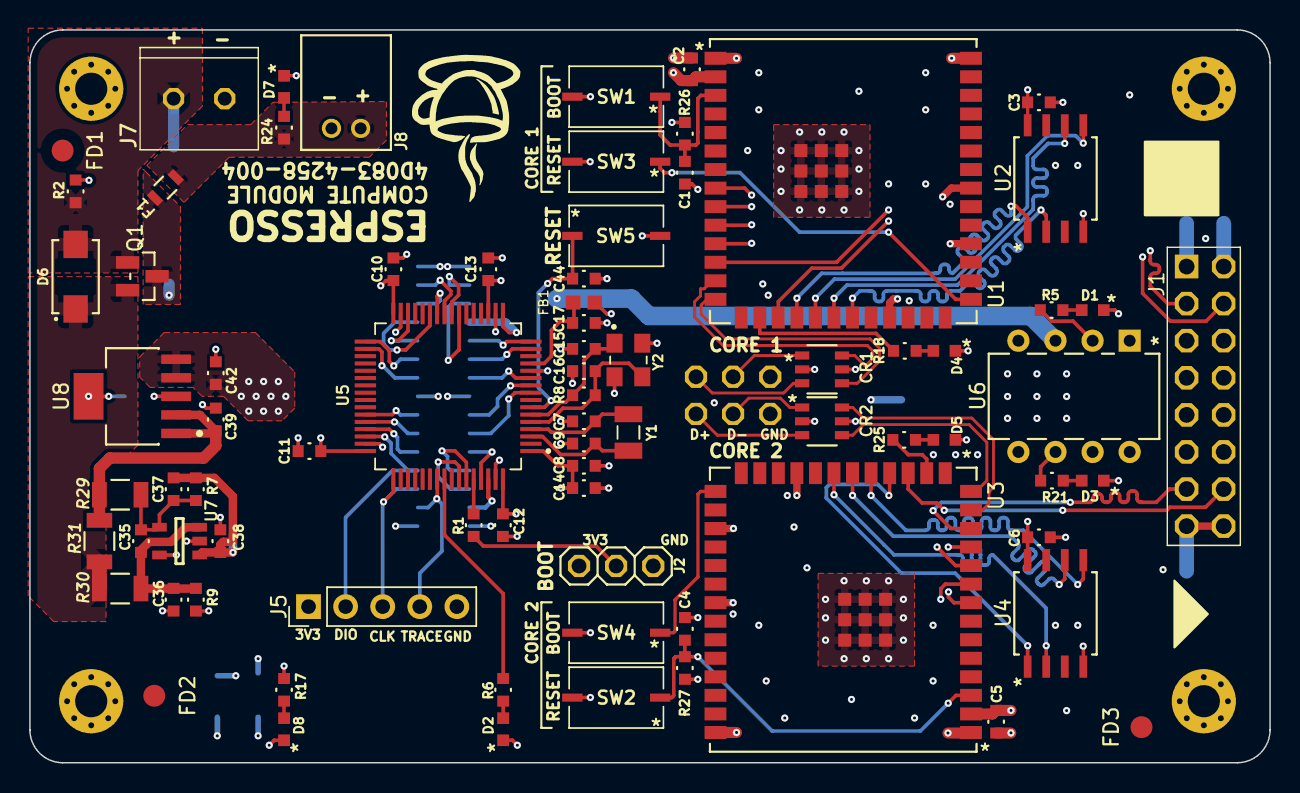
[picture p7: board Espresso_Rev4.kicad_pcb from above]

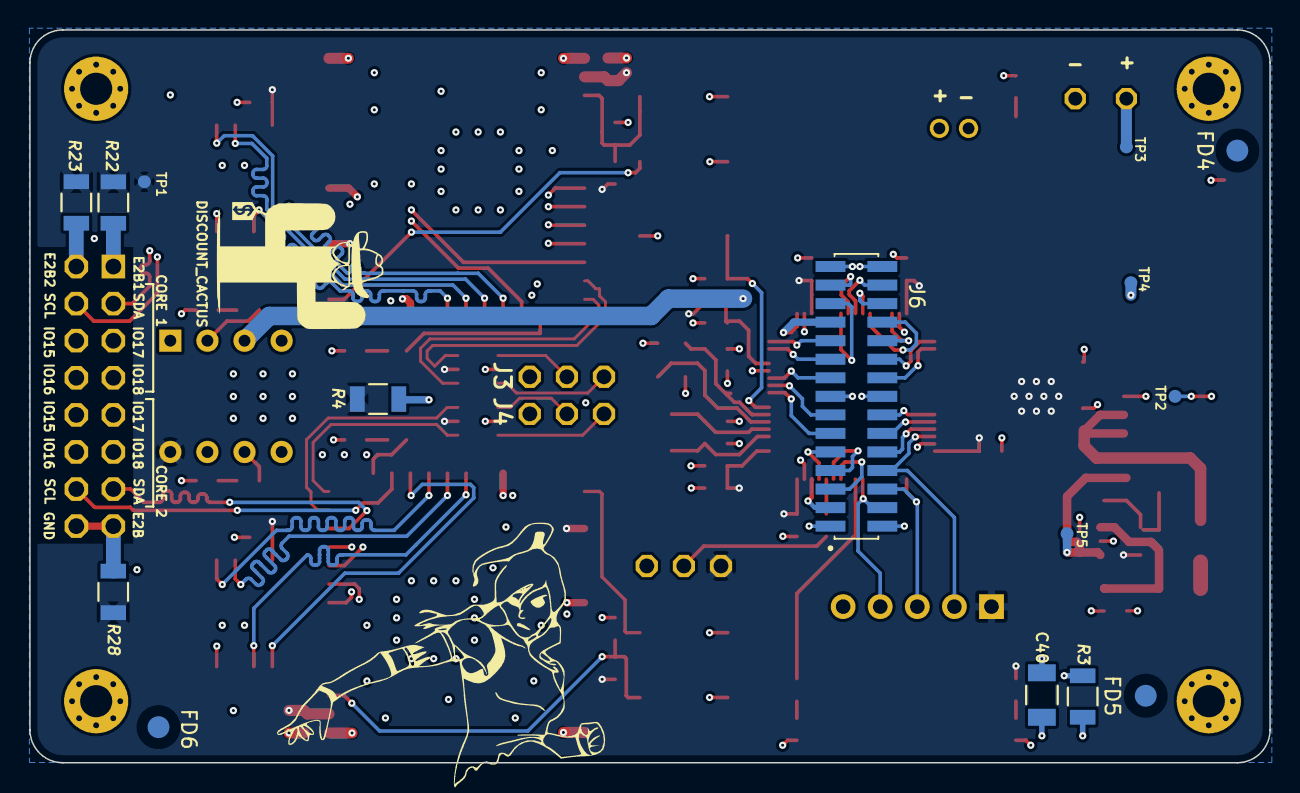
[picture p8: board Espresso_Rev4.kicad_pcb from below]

Board: 4 copper layers, 84.9 x 50.2 mm, 98 parts (15 on the bottom side), 89 nets.

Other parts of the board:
MH1, MH2, MH3, MH4: MountingHole_2.2mm_M2_Pad_Via

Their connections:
/SHIELD: MH1.1, MH2.1, MH3.1, MH4.1; also elsewhere on the board

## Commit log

2024-08-28 Initial KiCad project upload
    [BOM_Espresso_Rev41.csv, Espresso_Rev4.kicad_sch, Power.kicad_sch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]
2024-08-30 Updated BOM
    Corrected part number for 4.7 kohm resistor
    [BOM_Espresso_Rev41.csv]
2024-08-30 Removed unused schematic file
    [STM32_ETH.kicad_sch]
2025-05-11 Updated fab files
    [BOM_Espresso_Rev41.csv, Espresso_Rev4.kicad_pcb, Espresso_Rev4.kicad_sch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]
2025-08-02 Updated files
    [Espresso_Rev4_5_BOM.csv]
